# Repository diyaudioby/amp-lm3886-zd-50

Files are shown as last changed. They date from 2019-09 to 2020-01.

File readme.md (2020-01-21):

## LM3886 ZD-50

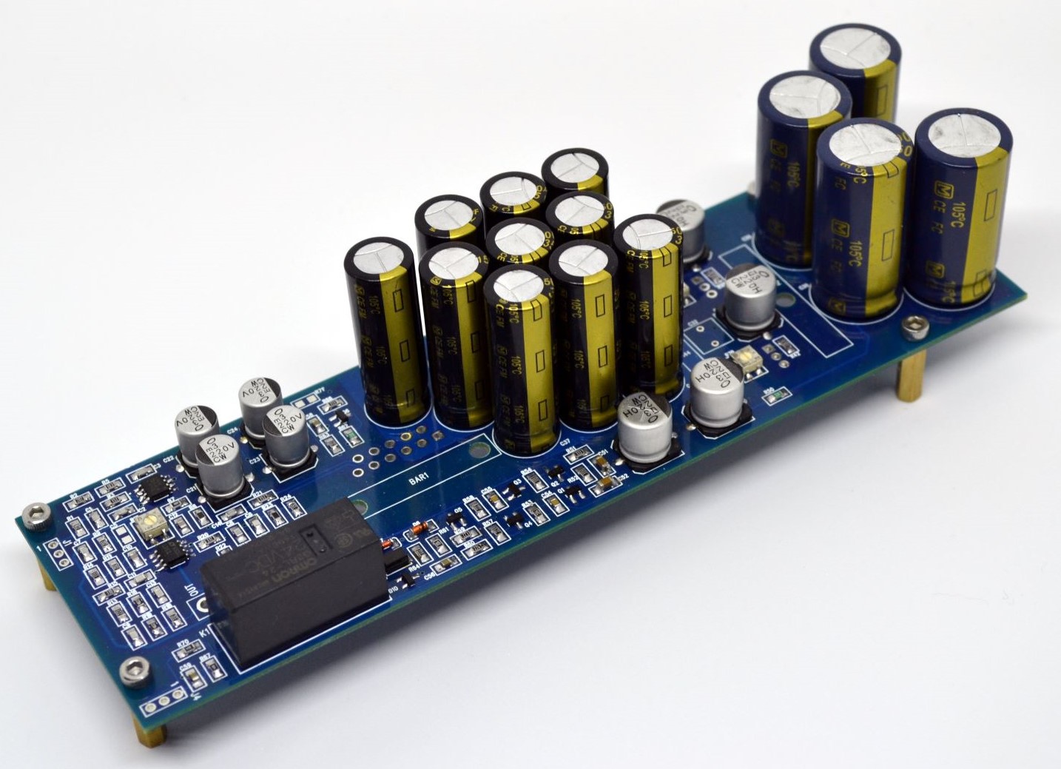
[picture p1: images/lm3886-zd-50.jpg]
lm3886-zd-50


### Description
One of the best hi-fi lm3886 amplifier.

### Source
- [https://www.s-audio.com/](https://www.s-audio.com/)

### Authors
- Shematic and PCB design - [Nick](http://forum.vegalab.ru/member.php?u=939)

### Links
- [http://forum.vegalab.ru/showthread.php?t=20617](http://forum.vegalab.ru/showthread.php?t=20617)

### Buy parts for assembling
- [Order PCB from PCBWay](https://www.pcbway.com/project/shareproject/lm3886_zd_50.html)

### Related projects
- [Power supply for LM3886 ZD-50](https://github.com/diyaudioby/ps-zd-50)
- [Softstart for LM3886 ZD-50](https://github.com/diyaudioby/ss-zd-50)

### Folder structure
Most folder names are self explanatory.
- 3d - contains 3d models of PCB
- bom - contains the bill of materials
- docs - contains drawings and images outputs of schematic and PCB files, assembling manuals
- firmware - contains compiled binary files
- gerbers - contains zip file of the PCB Gerbers and drill drawings for manufacture
- images - contain photo of assembling prototype
- pcb - contains the original schematic and PCB design files (Altium Designer,  KiCAD, SprintLayout, etc)
- soft - contains custom software using, for example, for operate with this device 
- source - contains project souce code (sketchs for Arduino, files C/C++, etc)

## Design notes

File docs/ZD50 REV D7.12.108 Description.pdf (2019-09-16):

## Усилитель мощности S-AUDIO ZD-50

Очень высокие характеристики данного усилителя достигаются за счёт глубокой ОС, главным образом в звуковой области частот. Усилитель основан на широко известной микросхеме LM3886. Глубокая ОС достигается путём добавления ещё одного, "более высококачественного" ОУ. Таким образом глубина ОС на 20KHz достигает 70dB и больше на более низких частотах.
Для сравнения у обычного включения LM3886 с Ку=12 глубина ОС на 20KHz всего около 30dB. Т.е. глубина ОС в звуковом диапазоне у данного усилителя минимум на 40dB (в 100 раз) больше, чем у стандартного включения и соответственно потенциально искажения в звуковом диапазоне на столько же меньше.
Уменьшаются также шумы, они теперь определяются входным ОУ. Хорошая устойчивость при такой глубине ОС достигается благодаря многопетлевой ОС и "хитрой" частотной корекции, с заходом за 180 градусов. Схема основана на идее композитного операционного усилителя [1], но значительно усовершенствована. Частота единичного усиления в петле ОС всего 1MHz, что делает схему не столь критичной к монтажу и улучшает повторяемость. Также благодаря "хитрой" корекции входной ОУ работает с очень малым сигналом (можно сказать как селектор нелинейных искажений). На его выходе в нормальном режиме работы усилителя всего около 100mV [График 1]. Т.е он работает в очень линейном режиме, можно сказать что в плане искажений его характеристики приближаются к идеальному ОУ. Исследование работы множества прототипов сделало ясным тот факт, что искажения реального усилителя определяются конструкцией усилителя. Главным источником искажений являются магнитные поля от цепей питания LM3886, так как они содержат компоненты выпрямленного выходного тока (сигнала). Наводясь на вход усилителя и цепи ОС это приводит к повышению, главным образом чётных, гармоник на ВЧ сигналах (выше 2-3KHz). Для минимизации данного эфекта желательно ставить шунтирущие конденсаторы как можно ближе к LM3886 и минимизировать индуктивность цепей питания. Реально замерянные гармонические искажения у последнего прототипа (версия D7.12.86) на 10KHz 50W 4Ohm около 0.0001%.
График Боде показывает глубину ООС от частоты

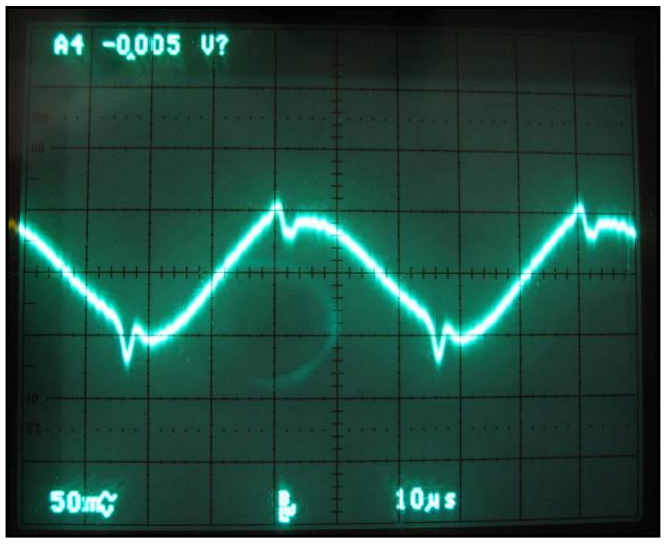
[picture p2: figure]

и фазовый набег. Красным цветом - без U2, т.е. почти стандартное включение LM3886 с усилением около 20, дан для сравнения [График 2]. При обеспечении критерия устойчивости Найквиста, фаза может заходить за 180 градусов на частотах ниже (и выше) частоты ед. усиления ОС, в данном случает это около 1MHz. Как видно из графика фазовый запас усилителя составляет около 40 градусов. Также видно что срез не 6дБ на октаву, а 12dB на октаву, так как первые 2 полюса довольно низкочастотные (это полюса самих U2 и U3), хотя с LT1363 второй полюс около 10KHz. В районе 50KHz находится ещё один полюс, образованный коррекцией U2, а в районе 250KHz находятся 2 нуля. Т.е коррекция по сути 3-х полюсная, с небольшим заходом за 180 градусов. График для LM318 дан при номиналах указанных ниже.

График 1. Напряжение на выходе U2.

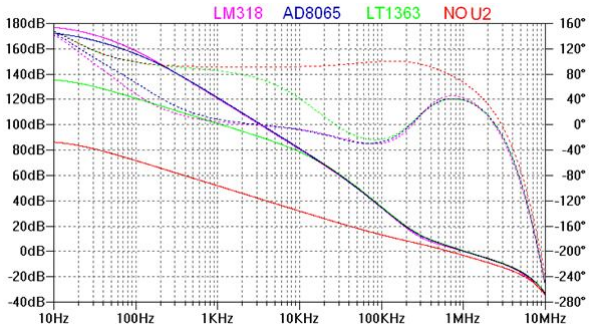
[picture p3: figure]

Рекомендуемые ОУ на место U2 - LM318, AD8065, LT1363. Для оптимальной работы усилителя на базе LM318, нужно изменить С14=68pF, R21=510, R22=220.
Чтобы повысить помехоустойчивость, были установлены цепочки C8, R12 и C11, R15. Они уменьшают коэф. передачи ОС выше 10мГц, тем самым уменьшают уровень помех выше этой частоты на инверсных входах обоих ОУ. В принципе их тоже можно не ставить, так как практически значимый эффект от них необнаружен. С7 - составной, параллельно 390pF запаивается чего то типа 22...47pF.
На схеме нет выходного фильтра - я использовал 18 витков на 8 мм оправе провод 1.5 мм и параллельно 10 ом резистор, они были размещены прямо на выходных клемах. Также параллельно выходным клемам желательно поставить последовательную цепочку из плёночного 0.1µF и 2Вт 10 Ohm резистора. Для питания одного канала усилителя я использовал 2 моста из диодов шоттки и соответсвенно 2 конденсатора 22000µF x 50V.
Для достижения описанных характеристик усилитель нужно делать исключительно как двойное моно.
При соблюдении номиналов и точности входных цепей и цепей ОС, необходимости в настройке нет. Иначе желательно подобрать R22 по минимуму напряжения на выходе U2, подав на вход синус 100Hz около 0.25 вольта и C7 по минимуму напряжения на выходе U2, подав на вход синус 20KHz около 0.25 вольта.

Литература:
1. Yewen J. High-precision composite op-amps.
Electronics & Wireless World, vol.93, no.1612, Feb. 1987, pp. 227-8.
2. С. Агеев. Сверхлинейный УМЗЧ с глубокой ООС. Радио, 10/1999, 11/1999.
3. B. J. Lurie, Paul J. Classical Feedback Control with MATLAB. ISBN 0-8247-0370-7

http://www.s-audio.com/
© 2007, 2008 Николай Швыдкий

График 2. Глубина ОС усилителя и фазовый набег в петле ОС (график Боде).

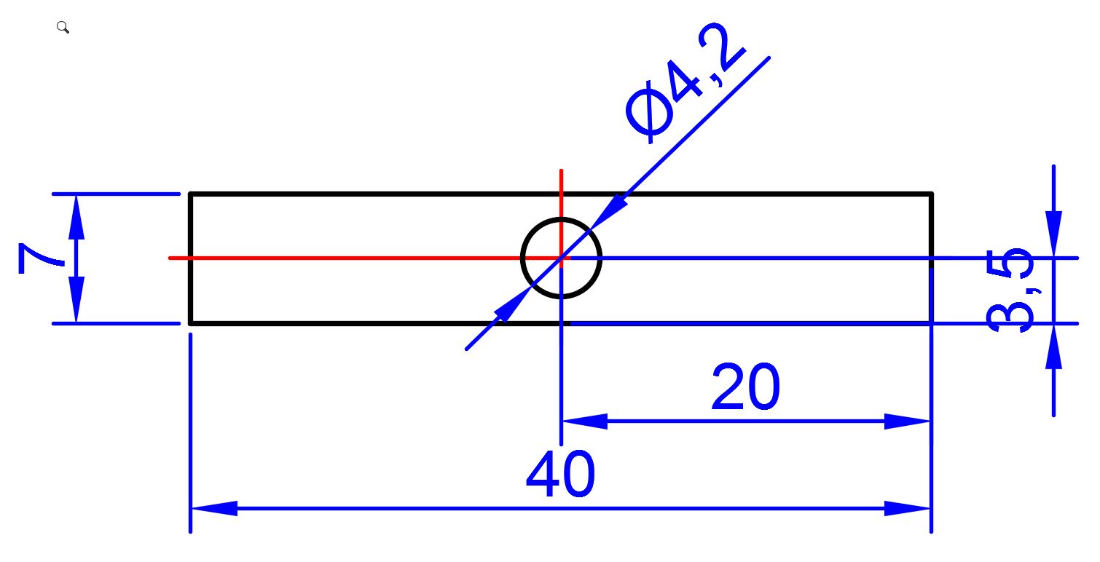
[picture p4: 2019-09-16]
docs/Bar_plane_2.JPG

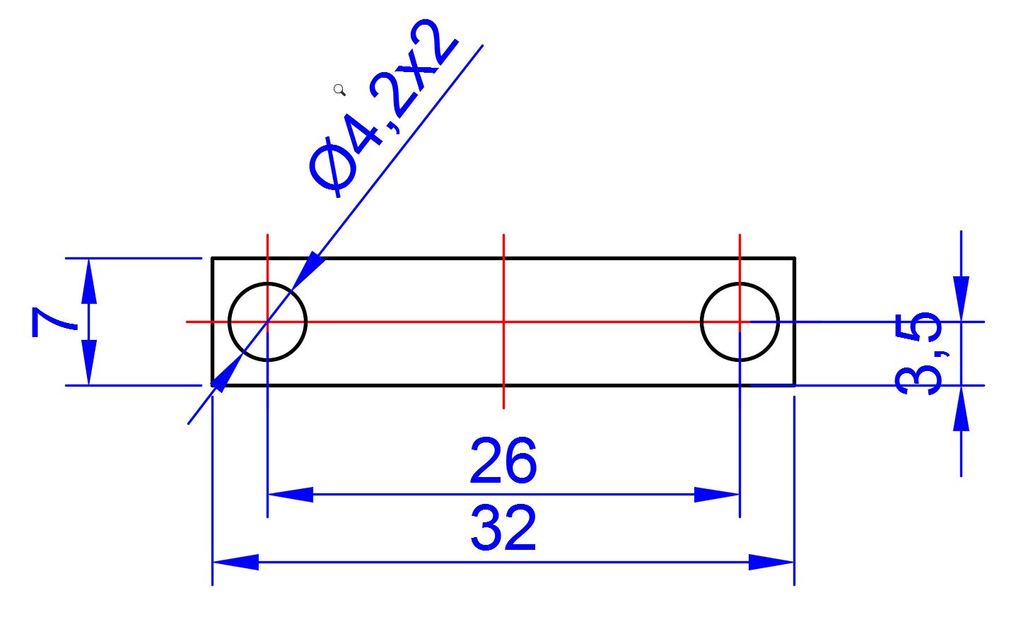
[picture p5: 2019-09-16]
docs/Bar_plane_1.JPG

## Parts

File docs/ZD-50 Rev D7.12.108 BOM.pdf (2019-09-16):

S-AUDIO ZD-50 Main Board | Rev. D7.MB12.108
Part Name | Reference | Additional info | Part Number | Case/Lead Style | Digikey Part Number | Alternative | Qty | Price | Total
Integrated Circuits
AD8065 | U1 | | AD8065ARZ | SOIC-8 | AD8065ARZ-ND | | 1 | 4.21 | 4.21
LT1363 | U2 | | LT1363CS8#PBF | SOIC-8 | LT1363CS8#PBF-ND | AD8065 | 1 | 5 | 5
LM3886T | U3 | | LM3886T/NOPB | TO-220-11 | LM3886T-ND | | 1 | 6.62 | 6.62
LM1084 | U4, U5 | | LM1084IT | TO-220-3 | LM1084IT-ADJ-ND | LT1083 | 2 | 3.13 | 6.26
LM317EMP | U6 | | LM317EMP/NOPB | SOT-223 | LM317EMPCT-ND | | 1 | 1.53 | 1.53
Transistors/Diodes
MMBTA06 | Q1, Q2, Q3, Q4 | | MMBTA06 | SOT-23-3 | MMBTA06FSCT-ND | | 4 | 0.22 | 0.88
MMBTA56 | Q5, Q6, Q7, Q8 | | MMBTA56 | SOT-23-3 | MMBTA56FSCT-ND | | 4 | 0.18 | 0.72
FLZ12V | D1, D2, D6, D9 | | FLZ12VA | SOD-80 | FLZ12VACT-ND | | 4 | 0.11 | 0.44
ES3BB | D3, D4 | | ES3BB-13-F | DO-214AA | ES3BB-FDICT-ND | | 2 | 0.96 | 1.92
ES1D | D5, D8 | | ES1D | DO-214AC | ES1DFSCT-ND | | 2 | 0.37 | 0.74
LL4148 | D7 | | FDLL4148 | SOD-80 | FDLL4148CT-ND | | 1 | 0.08 | 0.08
TL431 | D10 | | TL431IDBZR | SOT-23-3 | 296-17332-1-ND | | 1 | 0.45 | 0.45
Capacitors
220p | C1, C3, C4 | 50V | ECJ-2VC1H221J | C0805 | PCC221CGCT-ND | | 3 | 0.049 | 0.147
470p | C2 | 50V | ECJ-2VC1H471J | C0805 | PCC471CGCT-ND | | 1 | 0.049 | 0.049
100p | C6 | 50V | ECJ-2VC1H101J | C0805 | PCC101CGCT-ND | | 1 | 0.049 | 0.049
390p | C7*(420P), C9 | 50V | ECJ-2VC1H391J | C0805 | PCC391CGCT-ND | | 2 | 0.049 | 0.098
15p | C8, C14 | 50V | ECJ-2VC1H150J | C0805 | PCC150CNCT-ND | | 2 | 0.097 | 0.194
5p | C10, C12 | 50V | ECJ-2VC1H050C | C0805 | PCC050CNCT-ND | | 2 | 0.097 | 0.194
47p | C11 | 50V | ECJ-2VC1H470J | C0805 | PCC470CGCT-ND | | 1 | 0.049 | 0.049
10p | C13, C15 | 200V | ECJ-2VC2D100D | C0805 | PCC1971CT-ND | | 2 | 0.11 | 0.22
10µ | C17, C18, C19, C20, C51, C52, C57, C60 | 25V | ECJ-3YB1E106M | C1206 | PCC2326CT-ND | | 8 | 0.543 | 4.344
220µ | C21, C22, C23, C24 | 25V | EEV-FK1E221P | SMT (Size F) | PCE3409CT-ND | | 4 | 0.72 | 2.88
2200µ | C27, C28, C29, C30 | 50V | EEU-FC1H222 | TH (D18LS7.5LD0.8) | P10335-ND | | 4 | 2.6 | 10.4
0.82u | C31, C32 | 50V | ECQ-V1H824JL | TH (L7.3T6.8LS5.0LD0.5) | P4674-ND | | 2 | 0.323 | 0.646
220u | C33, C34, C50, C53 | 50V | EEV-FK1H221P | SMT (Size G) | PCE3474CT-ND | | 4 | 0.844 | 3.376
1500µ | C35, C36, C37, C38, C39, C40, C41, C42, C43, C44 | 35V | EEU-FM1V152L | TH (D12.5LS5LD0.8) | P12409-ND | | 10 | 1.34 | 13.4
10n | C54, C55 | 50V | ECJ-2VB1H103K | C0805 | PCC103BNCT-ND | | 2 | 0.041 | 0.082
0.1µ | C56, C58, C59 | 50V | ECJ-2VB1C104K | C0805 | PCC1812CT-ND | | 3 | 0.089 | 0.267

Resistors
8K20 | R1 | 0.1W | RG2012P-822-B-T5 | R0805 | RG20P8.2KBCT-ND | RR12P8.06KDCT-ND | 1 | 0.578 | 0.578
2K00 | R2, R9, R11 | 0.1W | RG2012P-202-B-T5 | R0805 | RG20P2.0KBCT-ND | RR12P2.0KDCT-ND | 3 | 0.578 | 1.734
1K5 | R3, R21 | 0.1W | RR1220P-152-D | R0805 | RR12P1.5KDCT-ND | | 2 | 0.14 | 0.28
100 | R4, R40, R42 | 0.1W | RR1220P-101-D | R0805 | RR12P100DCT-ND | | 3 | 0.14 | 0.42
10K0 | R5 | 0.1W | RG2012P-103-B-T5 | R0805 | RG20P10.0KBCT-ND | RR12P10.0KDCT-ND | 1 | 0.578 | 0.578
1K | R6 | 0.1W | RR1220P-102-D | R0805 | RR12P1.0KDCT-ND | | 1 | 0.14 | 0.14
0 | R7 | 0.1W | ERJ-6GEY0R00V | R0805 | P0.0ACT-ND | | 1 | 0.077 | 0.077
4K02 | R8 | 0.1W | RG2012P-4021-B-T5 | R0805 | RG20P4.02KBCT-ND | RR12P4.02KDCT-ND | 1 | 0.578 | 0.578
510 | R10 | 0.1W | RR1220P-511-D | R0805 | RR12P510DCT-ND | | 1 | 0.14 | 0.14
33 | R12, R15 | 0.1W | RP2012S-330-F | R0805 | RR12Q33DCT-ND | | 2 | 0.14 | 0.28
220 | R13 | 0.1W | RR1220P-221-D | R0805 | RR12P220DCT-ND | | 1 | 0.14 | 0.14
33K | R14, R51, R52, R54, R66 | 0.1W | RR1220P-333-D | R0805 | RR12P33.0KDCT-ND | | 5 | 0.14 | 0.7
40K2 | R16, R19 | 0.1W | RG2012P-4022-B-T5 | R0805 | RG20P40.2KBCT-ND | RR12P40.2KDCT-ND | 2 | 0.578 | 1.156
10K Trimmer | R17 | 0.1W | 3314G-1-103E | SMD (Size 6.2x5) | 3314G-103ECT-ND | | 1 | 1.8 | 1.8
3K3 | R18, R20, R24 | 0.1W | RR1220P-332-D | R0805 | RR12P3.3KDCT-ND | | 3 | 0.14 | 0.42
150 | R22 | 0.1W | RR1220P-151-D | R0805 | RR12P150DCT-ND | | 1 | 0.14 | 0.14
80K6 | R23 (*80K9) | 0.1W | RG2012P-8062-B-T5 | R0805 | RG20P80.6KBCT-ND | RR12P80.6KDCT-ND | 1 | 0.578 | 0.578
1 | R26, R27, R28, R29 | 0.1W | RL1220S-1R0-F | R0805 | RL12S1.00FCT-ND | | 4 | 0.344 | 1.376
300 | R30, R31, R32, R33 | 0.5W | ERJ-P14J301U | R1210 | P300ASCT-ND | | 4 | 0.356 | 1.424
2K | R36, R38 | 1W | CRCW25122K00JNEG | R2512 | 541-2.0KXCT-ND | | 2 | 0.399 | 0.798
500 Trimmer | R37, R39 | 0.1W | 3314G-1-501E | SMD (Size 6.2x5) | 3314G-501ECT-ND | | 2 | 1.8 | 3.6
120 | R41, R43 | 0.1W | RR1220P-121-D | R0805 | RR12P120DCT-ND | | 2 | 0.14 | 0.28
560 | R44, R45 | 2W | PR02000205600JR500 | TH (PR02LS17.8LD0.8) | PPC560W-2CT-ND | PPC560W-2CT-ND | 2 | 0.604 | 1.208
33 | R50, R62 | 0.33W | RP2012S-330-F | R0805 | RP20S33FCT-ND | | 2 | 0.536 | 1.072
510K | R53 | 0.1W | RR1220P-514-D | R0805 | RR12P510KDCT-ND | | 1 | 0.14 | 0.14
270 | R55 | 0.1W | RR1220P-271-D | R0805 | RR12P270DCT-ND | | 1 | 0.14 | 0.14
4K7 | R56, R65, R67, R68, R70 | 0.25W | ERJ-P06J472V | R0805 | P4.7KADCT-ND | | 5 | 0.165 | 0.825
22K | R57, R59, R63 | 0.1W | RR1220P-223-D | R0805 | RR12P22.0KDCT-ND | | 3 | 0.14 | 0.42
2K2 | R58, R64 | 0.1W | RR1220P-222-D | R0805 | RR12P2.2KDCT-ND | | 2 | 0.14 | 0.28
220K | R60 | 0.1W | RR1220P-224-D | R0805 | RR12P220KDCT-ND | | 1 | 0.14 | 0.14
100K | R61 | 0.1W | RR1220P-104-D | R0805 | RR12P100KDCT-ND | | 1 | 0.14 | 0.14
Relay
G2RL-24 | K1 | | G2RL-24-DC24 | TH | Z148-ND | | 1 | 4.03 | 4.03
Connectors
3 Pins Signal | J1 | To be defined? | | TH | | | | | 0
4 Pins Power | J2 | To be defined? | | TH | | | | | 0
2 Pins Signal | J3 | To be defined? | | TH | | | | | 0
2 Pins Power | J4 | To be defined? | | TH | | | | | 0
Total, USD | 90.857

Notes:
TH means Through-hole

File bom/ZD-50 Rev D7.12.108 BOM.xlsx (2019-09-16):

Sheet: Main Board
 |  |  | S-AUDIO ZD-50 Main Board |  | Rev. D7.MB12.108
 | Part Name | Reference | Additional info | Part Number | Case/Lead Style | Digikey Part Number | Alternative | Qty | Price | Total
 | Integrated Circuits
 | AD8065 | U1 |  | AD8065ARZ | SOIC-8 | AD8065ARZ-ND (http://search.digikey.com/scripts/DkSearch/dksus.dll?Detail?name=AD8065ARZ-ND) |  | 1 | 4.21 | 4.21
 | LT1363 | U2 |  | LT1363CS8#PBF | SOIC-8 | LT1363CS8#PBF-ND (http://search.digikey.com/scripts/DkSearch/dksus.dll?Detail?name=LT1363CS8%23PBF-ND) | AD8065 | 1 | 5 | 5
 | LM3886T | U3 |  | LM3886T/NOPB | TO-220-11 | LM3886T-ND (http://search.digikey.com/scripts/DkSearch/dksus.dll?Detail?name=LM3886T-ND) |  | 1 | 6.62 | 6.62
 | LM1084 | U4, U5 |  | LM1084IT | TO-220-3 | LM1084IT-ADJ-ND (http://search.digikey.com/scripts/DkSearch/dksus.dll?Detail?name=LM1084IT-ADJ-ND) | LT1083 | 2 | 3.13 | 6.26
 | LM317EMP | U6 |  | LM317EMP/NOPB | SOT-223 | LM317EMPCT-ND (http://search.digikey.com/scripts/DkSearch/dksus.dll?Detail?name=LM317EMPCT-ND) |  | 1 | 1.53 | 1.53
 | Transistors/Diodes
 | MMBTA06 | Q1, Q2, Q3 |  | MMBTA06 | SOT-23-3 | MMBTA06FSCT-ND (http://search.digikey.com/scripts/DkSearch/dksus.dll?Detail?name=MMBTA06FSCT-ND) |  | 3 | 0.22 | 0.66
 | MMBTA56 | Q4, Q5, Q6 |  | MMBTA56 | SOT-23-3 | MMBTA56FSCT-ND (http://search.digikey.com/scripts/DkSearch/dksus.dll?Detail?name=MMBTA56FSCT-ND) |  | 3 | 0.18 | 0.54
 | FLZ12V | D1, D2, D6, D9 |  | FLZ12VA | SOD-80 | FLZ12VACT-ND (http://search.digikey.com/scripts/DkSearch/dksus.dll?Detail?name=FLZ12VACT-ND) |  | 4 | 0.11 | 0.44
 | ES3BB | D3, D4 |  | ES3BB-13-F | DO-214AA | ES3BB-FDICT-ND (http://search.digikey.com/scripts/DkSearch/dksus.dll?Detail?name=ES3BB-FDICT-ND) |  | 2 | 0.96 | 1.92
 | ES1D | D5, D8 |  | ES1D | DO-214AC | ES1DFSCT-ND (http://search.digikey.com/scripts/DkSearch/dksus.dll?Detail?name=ES1DFSCT-ND) |  | 2 | 0.37 | 0.74
 | LL4148 | D7 |  | FDLL4148 | SOD-80 | FDLL4148CT-ND (http://search.digikey.com/scripts/DkSearch/dksus.dll?Detail?name=FDLL4148CT-ND) |  | 1 | 0.08 | 0.08
 | TL431 | D10 |  | TL431IDBZR | SOT-23-3 | 296-17332-1-ND (http://search.digikey.com/scripts/DkSearch/dksus.dll?Detail?name=296-17332-1-ND) |  | 1 | 0.45 | 0.45
 | Capacitors
 | 220p | C1, C3 | 50V | ECJ-2VC1H221J | C0805 | PCC221CGCT-ND (http://search.digikey.com/scripts/DkSearch/dksus.dll?Detail?name=PCC221CGCT-ND) |  | 2 | 0.049 | 0.098
 | 470p | C2 | 50V | ECJ-2VC1H471J | C0805 | PCC471CGCT-ND (http://search.digikey.com/scripts/DkSearch/dksus.dll?Detail?name=PCC471CGCT-ND) |  | 1 | 0.049 | 0.049
 | 100p | C6 | 50V | ECJ-2VC1H101J | C0805 | PCC101CGCT-ND (http://search.digikey.com/scripts/DkSearch/dksus.dll?Detail?name=PCC101CGCT-ND) |  | 1 | 0.049 | 0.049
 | 390p | C7*(420P), C9 | 50V | ECJ-2VC1H391J | C0805 | PCC391CGCT-ND (http://search.digikey.com/scripts/DkSearch/dksus.dll?Detail?name=PCC391CGCT-ND) |  | 2 | 0.049 | 0.098
 | 15p | C8, C14 | 50V | ECJ-2VC1H150J | C0805 | PCC150CNCT-ND (http://search.digikey.com/scripts/DkSearch/dksus.dll?Detail?name=PCC150CNCT-ND) |  | 2 | 0.097 | 0.194
 | 5p | C10, C12 | 50V | ECJ-2VC1H050C | C0805 | PCC050CNCT-ND (http://search.digikey.com/scripts/DkSearch/dksus.dll?Detail?name=PCC050CNCT-ND) |  | 2 | 0.097 | 0.194
 | 47p | C11 | 50V | ECJ-2VC1H470J | C0805 | PCC470CGCT-ND (http://search.digikey.com/scripts/DkSearch/dksus.dll?Detail?name=PCC470CGCT-ND) |  | 1 | 0.049 | 0.049
 | 10p | C13, C15 | 200V | ECJ-2VC2D100D | C0805 | PCC1971CT-ND (http://search.digikey.com/scripts/DkSearch/dksus.dll?Detail?name=PCC1971CT-ND) |  | 2 | 0.11 | 0.22
 | 10µ | C17, C18, C19, C20, C51, C52, C57, C60 | 25V | ECJ-3YB1E106M | C1206 | PCC2326CT-ND (http://search.digikey.com/scripts/DkSearch/dksus.dll?Detail?name=PCC2326CT-ND) |  | 8 | 0.543 | 4.344
 | 220µ | C21, C22, C23, C24 | 25V | EEV-FK1E221P | SMT (Size F) | PCE3409CT-ND (http://search.digikey.com/scripts/DkSearch/dksus.dll?Detail?name=PCE3409CT-ND) |  | 4 | 0.72 | 2.88
 | 2200µ | C27, C28, C29, C30 | 50V | EEU-FC1H222 | TH (D18LS7.5LD0.8) | P10335-ND (http://search.digikey.com/scripts/DkSearch/dksus.dll?Detail?name=P10335-ND) |  | 4 | 2.6 | 10.4
 | 0.82u | C31, C32 | 50V | ECQ-V1H824JL | TH (L7.3T6.8LS5.0LD0.5) | P4674-ND (http://search.digikey.com/scripts/DkSearch/dksus.dll?Detail?name=P4674-ND) |  | 2 | 0.323 | 0.646
 | 220u | C33, C34, C50, C53 | 50V | EEV-FK1H221P | SMT (Size G) | PCE3474CT-ND (http://search.digikey.com/scripts/DkSearch/dksus.dll?Detail?name=PCE3474CT-ND) |  | 4 | 0.844 | 3.376
 | 1500µ | C35, C36, C37, C38, C39, C40, C41, C42, C43, C44 | 35V | EEU-FM1V152L | TH (D12.5LS5LD0.8) | P12409-ND (http://search.digikey.com/scripts/DkSearch/dksus.dll?Detail?name=P12409-ND) |  | 10 | 1.34 | 13.4
 | 10n | C54, C55 | 50V | ECJ-2VB1H103K | C0805 | PCC103BNCT-ND (http://search.digikey.com/scripts/DkSearch/dksus.dll?Detail?name=PCC103BNCT-ND) |  | 2 | 0.041 | 0.082
 | 0.1µ | C56, C58, C59 | 50V | ECJ-2VB1C104K | C0805 | PCC1812CT-ND (http://search.digikey.com/scripts/DkSearch/dksus.dll?Detail?name=PCC1812CT-ND) |  | 3 | 0.089 | 0.267
 | Resistors
 | 8K20 | R1 | 0.1W | RG2012P-822-B-T5 | R0805 | RG20P8.2KBCT-ND (http://search.digikey.com/scripts/DkSearch/dksus.dll?Detail?name=RG20P8.2KBCT-ND) | RR12P8.06KDCT-ND (http://search.digikey.com/scripts/DkSearch/dksus.dll?Detail?name=RR12P8.06KDCT-ND) | 1 | 0.578 | 0.578
 | 2K00 | R2, R9, R11 | 0.1W | RG2012P-202-B-T5 | R0805 | RG20P2.0KBCT-ND (http://search.digikey.com/scripts/DkSearch/dksus.dll?Detail?name=RG20P2.0KBCT-ND) | RR12P2.0KDCT-ND (http://search.digikey.com/scripts/DkSearch/dksus.dll?Detail?name=RR12P2.0KDCT-ND) | 3 | 0.578 | 1.734
 | 1K5 | R3, R21 | 0.1W | RR1220P-152-D | R0805 | RR12P1.5KDCT-ND (http://search.digikey.com/scripts/DkSearch/dksus.dll?Detail?name=RR12P1.5KDCT-ND) |  | 2 | 0.14 | 0.28
R4 нету | 100 | R40, R42 | 0.1W | RR1220P-101-D | R0805 | RR12P100DCT-ND (http://search.digikey.com/scripts/DkSearch/dksus.dll?Detail?name=RR12P100DCT-ND) |  | 2 | 0.14 | 0.28
 | 10K0 | R5 | 0.1W | RG2012P-103-B-T5 | R0805 | RG20P10.0KBCT-ND (http://search.digikey.com/scripts/DkSearch/dksus.dll?Detail?name=RG20P10.0KBCT-ND) | RR12P10.0KDCT-ND (http://search.digikey.com/scripts/DkSearch/dksus.dll?Detail?name=RR12P10.0KDCT-ND) | 1 | 0.578 | 0.578
 | 0 | R7 | 0.1W | ERJ-6GEY0R00V | R0805 | P0.0ACT-ND (http://search.digikey.com/scripts/DkSearch/dksus.dll?Detail?name=P0.0ACT-ND) |  | 1 | 0.077 | 0.077
 | 4K02 | R8 | 0.1W | RG2012P-4021-B-T5 | R0805 | RG20P4.02KBCT-ND (http://search.digikey.com/scripts/DkSearch/dksus.dll?Detail?name=RG20P4.02KBCT-ND) | RR12P4.02KDCT-ND (http://search.digikey.com/scripts/DkSearch/dksus.dll?Detail?name=RR12P4.02KDCT-ND) | 1 | 0.578 | 0.578
 | 510 | R10 | 0.1W | RR1220P-511-D | R0805 | RR12P510DCT-ND (http://search.digikey.com/scripts/DkSearch/dksus.dll?Detail?name=RR12P510DCT-ND) |  | 1 | 0.14 | 0.14
 | 33 | R12, R15 | 0.1W | RP2012S-330-F | R0805 | RR12Q33DCT-ND (http://search.digikey.com/scripts/DkSearch/dksus.dll?Detail?name=RR12Q33DCT-ND) |  | 2 | 0.14 | 0.28
 | 220 | R13 | 0.1W | RR1220P-221-D | R0805 | RR12P220DCT-ND (http://search.digikey.com/scripts/DkSearch/dksus.dll?Detail?name=RR12P220DCT-ND) |  | 1 | 0.14 | 0.14
 | 33K | R14, R51, R52, R54, R66 | 0.1W | RR1220P-333-D | R0805 | RR12P33.0KDCT-ND (http://search.digikey.com/scripts/DkSearch/dksus.dll?Detail?name=RR12P33.0KDCT-ND) |  | 5 | 0.14 | 0.7
 | 40K2 | R16, R19 | 0.1W | RG2012P-4022-B-T5 | R0805 | RG20P40.2KBCT-ND (http://search.digikey.com/scripts/DkSearch/dksus.dll?Detail?name=RG20P40.2KBCT-ND) | RR12P40.2KDCT-ND (http://search.digikey.com/scripts/DkSearch/dksus.dll?Detail?name=RR12P40.2KDCT-ND) | 2 | 0.578 | 1.156
 | 10K Trimmer | R17 | 0.1W | 3314G-1-103E | SMD (Size 6.2x5) | 3314G-103ECT-ND (http://search.digikey.com/scripts/DkSearch/dksus.dll?Detail?name=3314G-103ECT-ND) |  | 1 | 1.8 | 1.8
 | 3K3 | R18, R20, R24 | 0.1W | RR1220P-332-D | R0805 | RR12P3.3KDCT-ND (http://search.digikey.com/scripts/DkSearch/dksus.dll?Detail?name=RR12P3.3KDCT-ND) |  | 3 | 0.14 | 0.42
 | 150 | R22 | 0.1W | RR1220P-151-D | R0805 | RR12P150DCT-ND (http://search.digikey.com/scripts/DkSearch/dksus.dll?Detail?name=RR12P150DCT-ND) |  | 1 | 0.14 | 0.14
 | 80K6 | R23 (*80K9) | 0.1W | RG2012P-8062-B-T5 | R0805 | RG20P80.6KBCT-ND (http://search.digikey.com/scripts/DkSearch/dksus.dll?Detail?name=RG20P80.6KBCT-ND) | RR12P80.6KDCT-ND (http://search.digikey.com/scripts/DkSearch/dksus.dll?Detail?name=RR12P80.6KDCT-ND) | 1 | 0.578 | 0.578
 | 1 | R26, R27, R28, R29 | 0.1W | RL1220S-1R0-F | R0805 | RL12S1.00FCT-ND (http://search.digikey.com/scripts/DkSearch/dksus.dll?Detail?name=RL12S1.00FCT-ND) |  | 4 | 0.344 | 1.376
 | 300 | R30, R31, R32, R33 | 0.5W | ERJ-P14J301U | R1210 | P300ASCT-ND (http://search.digikey.com/scripts/DkSearch/dksus.dll?Detail?name=P300ASCT-ND) |  | 4 | 0.356 | 1.424
 | 2K | R36, R38 | 1W | CRCW25122K00JNEG | R2512 | 541-2.0KXCT-ND (http://search.digikey.com/scripts/DkSearch/dksus.dll?Detail?name=541-2.0KXCT-ND) |  | 2 | 0.399 | 0.798
 | 500 Trimmer | R37, R39 | 0.1W | 3314G-1-501E | SMD (Size 6.2x5) | 3314G-501ECT-ND (http://search.digikey.com/scripts/DkSearch/dksus.dll?Detail?name=3314G-501ECT-ND) |  | 2 | 1.8 | 3.6
 | 120 | R41, R43 | 0.1W | RR1220P-121-D | R0805 | RR12P120DCT-ND (http://search.digikey.com/scripts/DkSearch/dksus.dll?Detail?name=RR12P120DCT-ND) |  | 2 | 0.14 | 0.28
 | 560 | R44, R45 | 2W | PR02000205600JR500 | TH (PR02LS17.8LD0.8) | PPC560W-2CT-ND (http://search.digikey.com/scripts/DkSearch/dksus.dll?Detail?name=PPC560W-2CT-ND) | PPC560W-2CT-ND (http://search.digikey.com/scripts/DkSearch/dksus.dll?Detail?name=PPC560W-2CT-ND) | 2 | 0.604 | 1.208
 | 33 | R50, R62 | 0.33W | RP2012S-330-F | R0805 | RP20S33FCT-ND (http://search.digikey.com/scripts/DkSearch/dksus.dll?Detail?name=RP20S33FCT-ND) |  | 2 | 0.536 | 1.072
 | 510K | R53 | 0.1W | RR1220P-514-D | R0805 | RR12P510KDCT-ND (http://search.digikey.com/scripts/DkSearch/dksus.dll?Detail?name=RR12P510KDCT-ND) |  | 1 | 0.14 | 0.14
 | 270 | R55 | 0.1W | RR1220P-271-D | R0805 | RR12P270DCT-ND (http://search.digikey.com/scripts/DkSearch/dksus.dll?Detail?name=RR12P270DCT-ND) |  | 1 | 0.14 | 0.14
 | 4K7 | R56, R65, R67, R68, R70 | 0.25W | ERJ-P06J472V | R0805 | P4.7KADCT-ND (http://search.digikey.com/scripts/DkSearch/dksus.dll?Detail?name=P4.7KADCT-ND) |  | 5 | 0.165 | 0.825
 | 22K | R57, R59, R63 | 0.1W | RR1220P-223-D | R0805 | RR12P22.0KDCT-ND (http://search.digikey.com/scripts/DkSearch/dksus.dll?Detail?name=RR12P22.0KDCT-ND) |  | 3 | 0.14 | 0.42
 | 2K2 | R58, R64 | 0.1W | RR1220P-222-D | R0805 | RR12P2.2KDCT-ND (http://search.digikey.com/scripts/DkSearch/dksus.dll?Detail?name=RR12P2.2KDCT-ND) |  | 2 | 0.14 | 0.28
 | 220K | R60 | 0.1W | RR1220P-224-D | R0805 | RR12P220KDCT-ND (http://search.digikey.com/scripts/DkSearch/dksus.dll?Detail?name=RR12P220KDCT-ND) |  | 1 | 0.14 | 0.14
 | 100K | R61 | 0.1W | RR1220P-104-D | R0805 | RR12P100KDCT-ND (http://search.digikey.com/scripts/DkSearch/dksus.dll?Detail?name=RR12P100KDCT-ND) |  | 1 | 0.14 | 0.14
 | Relay
 | G2RL-24 | K1 |  | G2RL-24-DC24 | TH | Z148-ND (http://search.digikey.com/scripts/DkSearch/dksus.dll?Detail?name=Z148-ND) |  | 1 | 4.03 | 4.03
 | Connectors
 | 3 Pins Signal | J1 | To be defined? |  | TH |  |  |  |  | 0
 | 4 Pins Power | J2 | To be defined? |  | TH |  |  |  |  | 0
 | 2 Pins Signal | J3 | To be defined? |  | TH |  |  |  |  | 0
 | 2 Pins Power | J4 | To be defined? |  | TH |  |  |  |  | 0
 |  |  |  |  |  |  |  |  | Total, USD | 90.128
 | Notes:
 | TH means Through-hole

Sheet: Power Board
 |  | S-AUDIO ZD-50 POWER BOARD |  |  | Rev. D7.PB1.1
Part Name | Reference | Additional info | Part Number | Case/Lead Style | Digikey Part Number | Alternative | Qty | Price | Total
LED Red/Green |  |  | SSL-LX3059IGW | 3mm | 67-1327-ND (http://search.digikey.com/scripts/DkSearch/dksus.dll?Detail&name=67-1327-ND) |  | 2 | 0.75 | 1.5
22000uFx50V |  |  |  |  | P6946-ND |  | 4 | 8.21 | 32.84
bridge diodes ? |  |  |  |  |  |  | 16 |  | 0
Power switch |  |  |  |  | EG1890-ND | CH867-ND | 1 | 5.22 | 5.22
Power entry |  |  |  |  | 486-1035-ND |  | 1 | 4.68 | 4.68
Fuse drawer |  |  |  |  | 486-1037-ND |  |  |  | 0
Fuse |  |  |  |  | 507-1297-ND |  |  |  | 0
Ferrite bead |  |  |  |  | 240-2279-ND | ? 240-2494-ND | 3 |  | 0
TRANS. 120VA 2 X 25V |  | www.farnell.com | MCTA120/25 |  | 9530568 (farnell.com) |  | 2 | 22.69 | 68.07
 |  |  |  |  |  |  |  |  | 112.31
Notes:
1 per 2 channels
Zobel ? For switch and bridges ?

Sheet: Chassis
Heatsink |  |  | Alternative | Size
Fischer Elektronik SK 47 75 (http://www.farnell.com/) |  |  | HH8546 (https://www.soanarplus.com/) | 200x75
RCA connector
RCA-GY-FRH (http://www.vt4c.com/shop/program/main.php?cat_id=25&group_id=2&hit_cat=) |  |  |  |  | pair | $14
Binding posts
SPC-05AG (http://www.vt4c.com/shop/program/main.php?cat_id=8&group_id=2&hit_cat=) |  |  |  |  | pair | $9
Thermalpad
SP A1500 SIL PAD | www.farnell.com | 878-3667
LM mounting screws | 18-8 Stainless Steel Low Head Sckt Cap Screw 6-32 Thread, 3/4" Length | 93615A217 (http://www.mcmaster.com/itm/find.asp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) |  |  | 3

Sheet: Parts Cases
Semiconductors |  |  | c1 | ZEROD\C0805
SOIC-8 | LT1363 (http://www.linear.com/pc/downloadDocument.do?navId=H0,C1,C1154,C1009,C1022,P1108,D3603) |  | c10 | ZEROD\C0805
TO-220-11 | LM3886 (http://www.national.com/ds/LM/LM3886.pdf) |  | c11 | ZEROD\C0805
TO-220-3 | LM1084 (http://www.national.com/ds/LM/LM1084.pdf) | 1 - Adj, 2 - Out, 3 - In | c12 | ZEROD\C0805
SOT-223 |  | Layout\LM317EMP.png | c13 | ZEROD\C0805
SOD-80 (MLL-34) |  | Layout\FLZ12VA.png | c14 | ZEROD\C0805
DO-214AA (SMB) |  | Layout\ES3BB.png | c15 | ZEROD\C0805
DO-214AC (SMA) |  | Layout\ES1D.png | c16 | ZEROD\C1210
SOT-23-3 | TL431 (http://focus.ti.com/lit/ds/symlink/tl431a.pdf) | 1 - Cathode, 2 - Ref, 3 - Anode | c17 | ZEROD\C1206
SOT-23-3 |  | Layout\MMBTA06(56).png | c18 | ZEROD\C1206
 |  |  | c19 | ZEROD\C1206
Capacitors |  |  | c2 | ZEROD\C0805
SMT (Size G) | Panasonic FK (http://www.panasonic.com/industrial/components/pdf/pic_fk_series.pdf) | Layout\PANASONICFK.png | c20 | ZEROD\C1206
SMT (Size F) | Panasonic FK (http://www.panasonic.com/industrial/components/pdf/pic_fk_series.pdf) | Layout\PANASONICFK.png | c21 | ZEROD\CAPSMTF
TH (D18LS7.5LD0.8) | Panasonic FC (http://www.panasonic.com/industrial/components/pdf/ABA0000CE22.pdf) |  | c22 | ZEROD\CAPSMTF
TH (D12.5LS5LD0.8) | Panasonic FM (http://www.panasonic.com/industrial/components/pdf/ABA0000CE108.pdf) |  | c23 | ZEROD\CAPSMTF
TH (L7.3T6.8LS5.0LD0.5) | Panasonic ECQ-V1 (http://www.panasonic.com/industrial/components/pdf/abd0000ce8.pdf) |  | c24 | ZEROD\CAPSMTF
C0805 |  |  | c27 | ZEROD\CAPD18LS7.5LD0.8
C1206 |  |  | c28 | ZEROD\CAPD18LS7.5LD0.8
C1210 |  |  | c29 | ZEROD\CAPD18LS7.5LD0.8
 |  |  | c30 | ZEROD\CAPD18LS7.5LD0.8
 |  |  | c31 | ZEROD\CAPL7.3T6.8LS5.0LD0.5
Resistors |  |  | c32 | ZEROD\CAPL7.3T6.8LS5.0LD0.5
R0805 |  | Layout\RESISTORSSMD.png | c33 | ZEROD\CAPSMTG
R1210 |  | Layout\RESISTORSSMD.png | c34 | ZEROD\CAPSMTG
R2512 |  | Layout\RESISTORSSMD.png | c35 | ZEROD\CAPD12.5LS5LD0.8
SMD (Size 6.2x5) | Bourns 3314G (http://rocky.digikey.com/weblib/Bourns/Web%20Data/3314.pdf) | Layout\TRIMMER3314G-1.png | c36 | ZEROD\CAPD12.5LS5LD0.8
TH (PR02LS17.8LD0.8) | Vishay PR02 (http://www.vishay.com/docs/28729/pr010203.pdf) | Layout\PR03RES3W.png | c37 | ZEROD\CAPD12.5LS5LD0.8
 |  |  | c38 | ZEROD\CAPD12.5LS5LD0.8
 |  |  | c39 | ZEROD\CAPD12.5LS5LD0.8
 |  |  | c40 | ZEROD\CAPD12.5LS5LD0.8
 |  |  | c41 | ZEROD\CAPD12.5LS5LD0.8
 |  |  | c42 | ZEROD\CAPD12.5LS5LD0.8
 |  |  | c43 | ZEROD\CAPD12.5LS5LD0.8
 |  |  | c44 | ZEROD\CAPD12.5LS5LD0.8
 |  |  | c45 | ZEROD\C1210
 |  |  | c46 | ZEROD\C1210
 |  |  | c5 | ZEROD\C0805
 |  |  | c50 | ZEROD\CAPSMTG
 |  |  | c51 | ZEROD\C1206
 |  |  | c52 | ZEROD\C1206
 |  |  | c53 | ZEROD\CAPSMTG
 |  |  | c54 | ZEROD\C0805
 |  |  | c55 | ZEROD\C0805
 |  |  | c56 | ZEROD\C0805
 |  |  | c57 | ZEROD\C1206
 |  |  | c58 | ZEROD\C0805
 |  |  | c59 | ZEROD\C0805
 |  |  | c6 | ZEROD\C0805
 |  |  | c60 | ZEROD\C1206
 |  |  | c7 | ZEROD\C0805
 |  |  | c8 | ZEROD\C0805
 |  |  | c9 | ZEROD\C0805
 |  |  | d1 | ZEROD\SOD-80
 |  |  | d10 | ZEROD\SOT-23-3
 |  |  | d2 | ZEROD\SOD-80
 |  |  | d3 | ZEROD\DO-214AA
 |  |  | d4 | ZEROD\DO-214AA
 |  |  | d5 | ZEROD\DO-214AC
 |  |  | d6 | ZEROD\SOD-80
 |  |  | d7 | ZEROD\SOD-80
 |  |  | d8 | ZEROD\DO-214AC
 |  |  | d9 | ZEROD\SOD-80
 |  |  | j1 | ZEROD\CON-SIG-3
 |  |  | j2 | ZEROD\CON-POW-4
 |  |  | j3 | ZEROD\CON-POW-2
 |  |  | j4 | ZEROD\CON-SIG-2
 |  |  | k1 | ZEROD\RELAY-G2RL-24
 |  |  | q1 | ZEROD\SOT-23-3
 |  |  | q2 | ZEROD\SOT-23-3
 |  |  | q3 | ZEROD\SOT-23-3
 |  |  | q4 | ZEROD\SOT-23-3
 |  |  | q5 | ZEROD\SOT-23-3
 |  |  | q6 | ZEROD\SOT-23-3
 |  |  | r1 | ZEROD\R0805
 |  |  | r10 | ZEROD\R0805
 |  |  | r11 | ZEROD\R0805
 |  |  | r12 | ZEROD\R0805
 |  |  | r13 | ZEROD\R0805
 |  |  | r14 | ZEROD\R0805
 |  |  | r15 | ZEROD\R0805
 |  |  | r16 | ZEROD\R0805
 |  |  | r17 | ZEROD\R-BOURNS-3314G
 |  |  | r18 | ZEROD\R0805
 |  |  | r19 | ZEROD\R0805
 |  |  | r2 | ZEROD\R0805
 |  |  | r20 | ZEROD\R0805
 |  |  | r21 | ZEROD\R0805
 |  |  | r22 | ZEROD\R0805
 |  |  | r23 | ZEROD\R0805
 |  |  | r24 | ZEROD\R0805
 |  |  | r25 | ZEROD\R0805
 |  |  | r26 | ZEROD\R0805
 |  |  | r27 | ZEROD\R0805
 |  |  | r28 | ZEROD\R0805
 |  |  | r29 | ZEROD\R0805
 |  |  | r3 | ZEROD\R0805
 |  |  | r30 | ZEROD\R1210
 |  |  | r31 | ZEROD\R1210
 |  |  | r32 | ZEROD\R1210
 |  |  | r33 | ZEROD\R1210
 |  |  | r36 | ZEROD\R2512
 |  |  | r37 | ZEROD\R-BOURNS-3314G
 |  |  | r38 | ZEROD\R2512
 |  |  | r39 | ZEROD\R-BOURNS-3314G
 |  |  | r40 | ZEROD\R0805
 |  |  | r41 | ZEROD\R0805
 |  |  | r42 | ZEROD\R0805
 |  |  | r43 | ZEROD\R0805
 |  |  | r44 | ZEROD\RES-PR02
 |  |  | r45 | ZEROD\RES-PR02
 |  |  | r46 | ZEROD\R0805
 |  |  | r47 | ZEROD\R0805
 |  |  | r5 | ZEROD\R0805
 |  |  | r50 | ZEROD\R0805
 |  |  | r51 | ZEROD\R0805
 |  |  | r52 | ZEROD\R0805
 |  |  | r53 | ZEROD\R0805
 |  |  | r54 | ZEROD\R0805
 |  |  | r55 | ZEROD\R0805
 |  |  | r56 | ZEROD\R0805
 |  |  | r57 | ZEROD\R0805
 |  |  | r58 | ZEROD\R0805
 |  |  | r59 | ZEROD\R0805
 |  |  | r60 | ZEROD\R0805
 |  |  | r61 | ZEROD\R0805
 |  |  | r62 | ZEROD\R0805
 |  |  | r63 | ZEROD\R0805
 |  |  | r64 | ZEROD\R0805
 |  |  | r65 | ZEROD\R0805
 |  |  | r66 | ZEROD\R0805
 |  |  | r67 | ZEROD\R0805
 |  |  | r68 | ZEROD\R0805
 |  |  | r7 | ZEROD\R0805
 |  |  | r8 | ZEROD\R0805
 |  |  | r9 | ZEROD\R0805
 |  |  | u1 | ZEROD\SOIC-8
 |  |  | u2 | ZEROD\SOIC-8
 |  |  | u3 | ZEROD\TO-220-11-LAYING
 |  |  | u4 | ZEROD\TO-220-3-LAYING
 |  |  | u5 | ZEROD\TO-220-3-LAYING
 |  |  | u6 | ZEROD\SOT-223

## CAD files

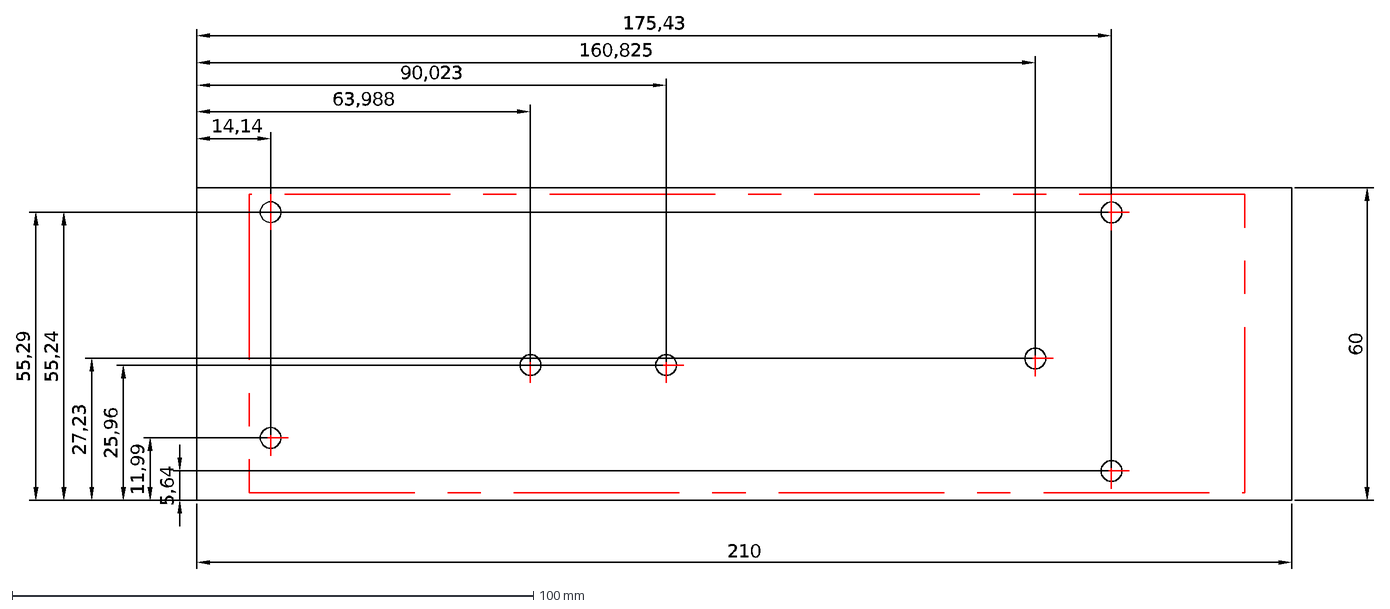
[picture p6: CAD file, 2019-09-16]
docs/heatsink-zd50.dxf
210
60
14,14
63,988
90,023
160,825
175,43
5,64
11,99
25,96
27,23
55,24
55,29

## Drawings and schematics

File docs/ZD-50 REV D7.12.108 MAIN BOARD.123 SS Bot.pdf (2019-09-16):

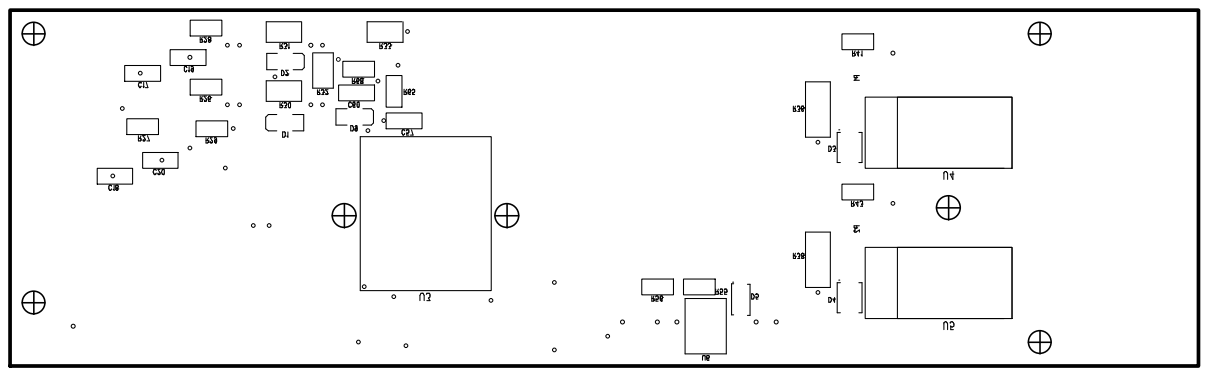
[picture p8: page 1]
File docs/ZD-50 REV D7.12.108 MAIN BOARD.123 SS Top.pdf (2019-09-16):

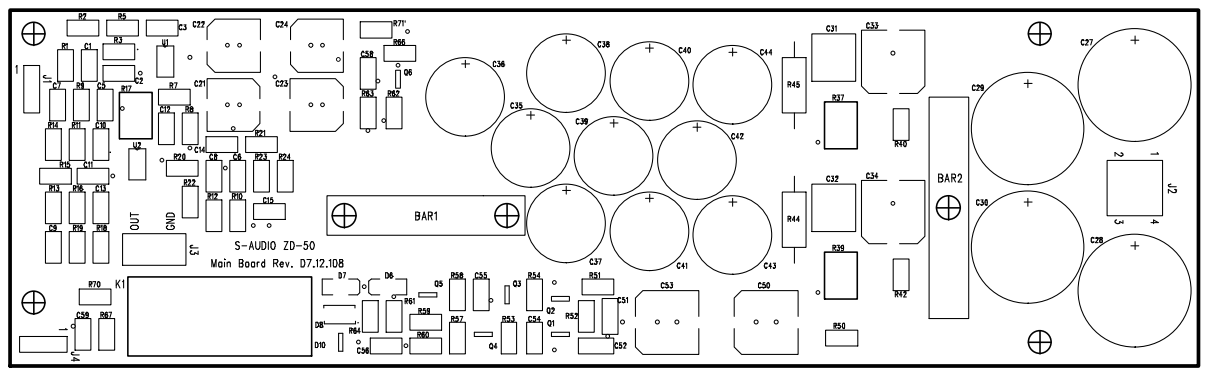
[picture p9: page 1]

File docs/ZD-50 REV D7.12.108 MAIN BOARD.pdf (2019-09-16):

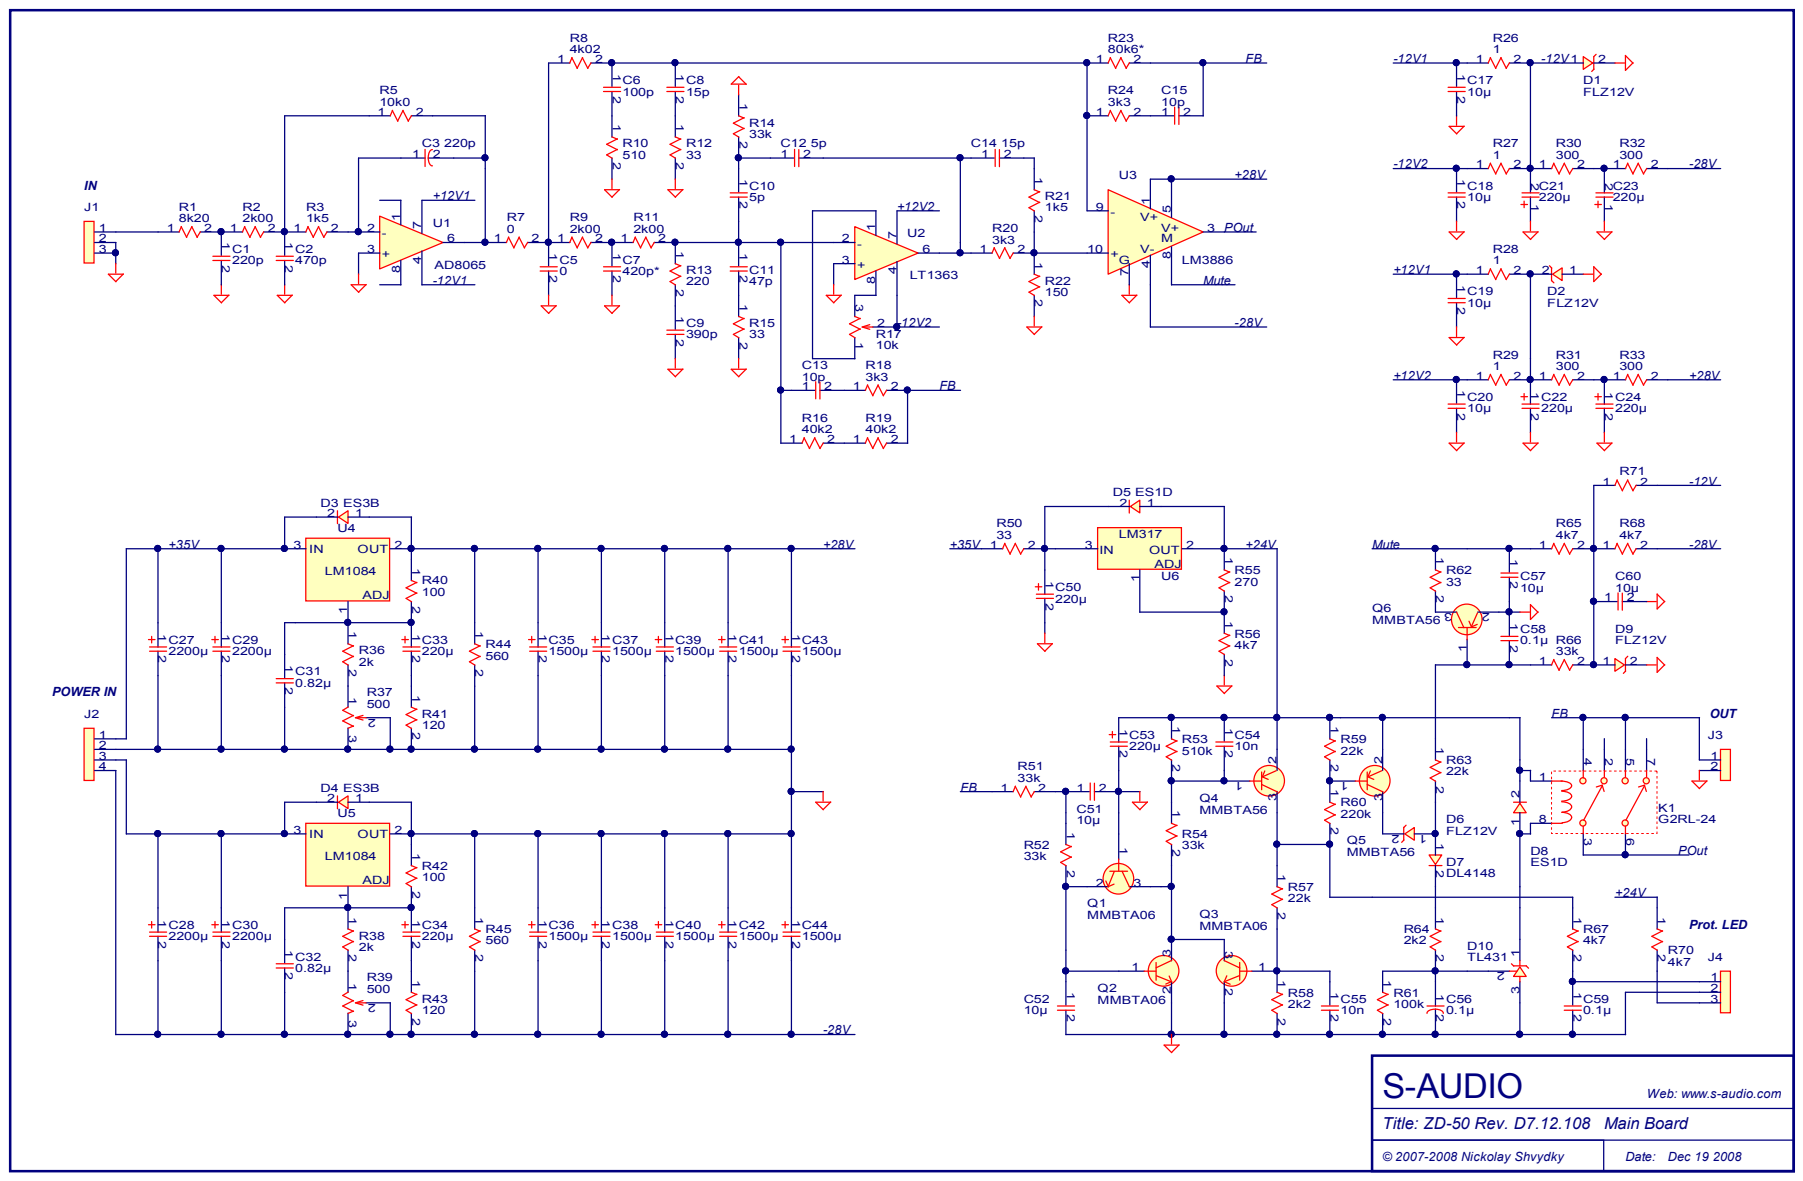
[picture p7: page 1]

Web: www.s-audio.com

Title: ZD-50 Rev. D7.12.108 Main Board
